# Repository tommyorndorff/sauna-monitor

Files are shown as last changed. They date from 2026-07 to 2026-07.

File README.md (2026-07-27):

# Wi-Fi Sauna Temperature Monitor (ESP32 + K-Type Thermocouple)

A DIY remote temperature monitor for a hot sauna. An ESP32 reads a K-type
thermocouple through a MAX31855 amplifier, runs [ESPHome](https://esphome.io), and
reports temperature over Wi-Fi to [Home Assistant](https://www.home-assistant.io),
which pushes a "sauna is ready" notification to your phone when it hits temperature.

Monitor-only build: it reports the temperature, it does not switch the heater.
Remote-starting a hardwired sauna heater is a separate, safety-critical project and
is out of scope here.

---

## Repository layout

The YAML in this guide is the documentation copy. The maintained, CI-validated
sources live in their own files:

| Path | What |
|---|---|
| [`esphome/sauna-monitor.yaml`](esphome/sauna-monitor.yaml) | ESPHome device config (copy `secrets.yaml.example` → `secrets.yaml`) |
| [`homeassistant/packages/sauna_monitor.yaml`](homeassistant/packages/sauna_monitor.yaml) | Home Assistant package: arming helper + notification automations |
| [`enclosure/`](enclosure/) | 3D-printable enclosure (parametric OpenSCAD) + STLs |
| [`docs/BOM.md`](docs/BOM.md) | Bill of materials with links |
| [`.github/workflows/ci.yml`](.github/workflows/ci.yml) | CI: yamllint + ESPHome + Home Assistant config validation |

---

## Design decisions

- The ESP32 lives outside the hot room. Its silicon and Wi-Fi front-end top out
  around 85 °C, so it cannot survive sauna air. Only the thermocouple probe and its
  lead go into the sauna; the electronics sit in a sealed box on a cool exterior wall.
- K-type thermocouple, not a DS18B20. A DS18B20 is rated to ~125 °C and its cable
  jacket is often the weak point near a sauna ceiling. A K-type probe with a high-temp
  lead handles any sauna temperature with margin. The tradeoff is accuracy
  (~±2 °C vs ±0.5 °C), which does not matter for "is it ready yet."
- IP-rated enclosure protects against outdoor weather and sauna humidity. IP rating is
  about water, not heat, so box placement still matters.

Signal chain: K-type probe → MAX31855 (amplifier + cold-junction compensation) →
SPI → ESP32 → Wi-Fi → Home Assistant.

---

## Bill of materials

Full parts list with purchase links: [`docs/BOM.md`](docs/BOM.md). Summary:

| # | Part | Spec / notes | Approx. |
|---|---|---|---|
| 1 | ESP32 dev board | Standard devkit (ESP32-DevKitC / WROOM-32) | ~$6 |
| 2 | MAX31855 K-type amplifier breakout | 3.3 V logic, SPI, read-only. Genuine MAX31855 preferred; some clones ship a MAX6675 (works, lower resolution) | $5–15 |
| 3 | K-type thermocouple probe | Ungrounded, high-temp lead (fiberglass / stainless braid, ≥400 °C). Threaded or ring-terminal tip for mounting | $8–15 |
| 4 | K-type extension wire/connector | Only if the probe lead won't reach the box. Must be K-type wire, never plain copper | $6 |
| 5 | Enclosure | 3D printed — see [`enclosure/`](enclosure/) (PETG/ASA). Filament + gasket cord only | — |
| 6 | Cable glands (IP68) | One sized to the thermocouple lead OD, one to the power cable OD | $8/pack |
| 7 | Desiccant packs or Gore vent plug | Prevents internal condensation in the sealed box | $5 |
| 8 | High-temp RTV silicone | Rated ~260–300 °C, to seal the wall penetration | $7 |
| 9 | 5 V USB supply + cable | Fed from a GFCI-protected outdoor outlet | $8 |
| 10 | Hookup wire / jumpers + heat-shrink | For the 5 SPI + power lines | $5 |
| 11 | Probe mount hardware | Stainless bracket/bolt to fix the tip near the ceiling | $5 |

Roughly $50–70 beyond the ESP32. Prices vary by vendor; check before buying.

Note: SPI does not use the 4.7 kΩ pull-up resistor that a DS18B20 (1-Wire) build
requires. If you're adapting a DS18B20 guide, drop that resistor.

---

## Wiring

MAX31855 is SPI and read-only, so it uses CLK, MISO (DO), and CS. There is no MOSI.

| MAX31855 pin | ESP32 pin (example) | Notes |
|---|---|---|
| VIN / VCC | 3.3 V | 3.3 V logic board — do not use a 5 V-only module |
| GND | GND | |
| SCK / CLK | GPIO18 | SPI clock |
| DO / SO (MISO) | GPIO19 | data out from the chip |
| CS | GPIO5 | chip select (any free GPIO) |

Thermocouple to the breakout screw terminals — polarity matters:

- K-type convention: yellow = + (positive), red = − (negative).
- Reversed leads read backwards / cold. If the reading moves the wrong way when heated,
  swap the two.
- If extending, splice with K-type wire or a K-type connector only. Plain copper creates
  a second thermocouple junction and a measurement error.

Layout rule: keep the MAX31855 close to the ESP32 (the thermocouple signal is
microvolt-level). Run the thermocouple wire as the long leg into the sauna; do not run
a long SPI cable.

---

## Enclosure, mounting & sealing

- Mount the box on a cool, shaded exterior surface of the sauna building.
- Probe tip goes a hand's width (~10–15 cm) below the ceiling, ideally above or near the
  heater where the air is hottest — the conventional meaning of "sauna temperature."
- Bring the thermocouple lead into the box through an IP68 gland; seal the wall
  penetration into the sauna with high-temp RTV silicone.
- Drop a desiccant pack (or fit a Gore vent plug) inside the box. A sealed enclosure with
  large temperature swings condenses internally — the classic "waterproof" failure.
- Keep the mains side to code for a wet outdoor location; power from a GFCI outlet.

The printable enclosure and print settings are in [`enclosure/`](enclosure/).

---

## Firmware (ESPHome)

Requires ESPHome 2025.x or newer (the `max31855` platform under the SPI bus). Put your
Wi-Fi credentials in `secrets.yaml`. The maintained config is
[`esphome/sauna-monitor.yaml`](esphome/sauna-monitor.yaml).

```yaml
esphome:
  name: sauna-monitor

esp32:
  board: esp32dev

wifi:
  ssid: !secret wifi_ssid
  password: !secret wifi_password

logger:
api:
  encryption:
    key: !secret api_key   # optional but recommended
ota:
  - platform: esphome

# MAX31855 is read-only: CLK + MISO only, no MOSI
spi:
  clk_pin: GPIO18
  miso_pin: GPIO19

sensor:
  - platform: max31855
    name: "Sauna Temperature"
    cs_pin: GPIO5
    update_interval: 10s
```

After the first flash, confirm the sensor appears in ESPHome logs and reads plausible
room temperature before you seal anything up. It publishes to Home Assistant as
`sensor.sauna_temperature` (°C).

---

## Home Assistant: ready notification

Requires the Home Assistant Companion app on your phone for the `notify.mobile_app_*`
service. Rename `notify.mobile_app_your_phone` to your device. The maintained package is
[`homeassistant/packages/sauna_monitor.yaml`](homeassistant/packages/sauna_monitor.yaml).

### Version A — basic (fires on every crossing)

```yaml
alias: Sauna Ready
description: Notify when the sauna reaches usable temperature
triggers:
  - trigger: numeric_state
    entity_id: sensor.sauna_temperature
    above: 80          # °C  (80 °C ≈ 176 °F) — set to taste
    for:
      minutes: 2       # must hold above threshold to ignore spikes
conditions: []
actions:
  - action: notify.mobile_app_your_phone
    data:
      title: "🔥 Sauna is ready"
      message: >
        Sauna hit {{ states('sensor.sauna_temperature') }} °C — good to go.
mode: single
```

The `numeric_state` trigger is edge-triggered, so it fires only on the upward crossing,
not continuously while the sauna holds temperature. The `for: 2 minutes` guards against a
brief overshoot firing it early.

### Version B — arming helper (recommended)

Prevents mid-session false alerts (for example, temp dips after throwing water, then
climbs back through 80 °C). You arm it when you start the heater; it self-disarms after
alerting.

1. Create the helper — Settings → Devices & Services → Helpers → Toggle →
   name it `Sauna Heating` (entity `input_boolean.sauna_heating`). Flip it on when you
   start the heater (dashboard button, phone, or a voice assistant).

2. Ready automation (armed, one-shot):

```yaml
alias: Sauna Ready (armed)
triggers:
  - trigger: numeric_state
    entity_id: sensor.sauna_temperature
    above: 80
    for:
      minutes: 2
conditions:
  - condition: state
    entity_id: input_boolean.sauna_heating
    state: "on"
actions:
  - action: notify.mobile_app_your_phone
    data:
      title: "🔥 Sauna is ready"
      message: >
        Sauna hit {{ states('sensor.sauna_temperature') }} °C — good to go.
  - action: input_boolean.turn_off        # disarm so it won't re-alert this session
    target:
      entity_id: input_boolean.sauna_heating
mode: single
```

3. Auto-disarm on cooldown (clears state if you armed but never went / cancelled):

```yaml
alias: Sauna Disarm on Cooldown
triggers:
  - trigger: numeric_state
    entity_id: sensor.sauna_temperature
    below: 40
    for:
      minutes: 10
conditions:
  - condition: state
    entity_id: input_boolean.sauna_heating
    state: "on"
actions:
  - action: input_boolean.turn_off
    target:
      entity_id: input_boolean.sauna_heating
mode: single
```

### Fahrenheit message (without changing firmware)

Replace the `message:` line in any automation above with:

```yaml
      message: >
        Sauna hit {{ (states('sensor.sauna_temperature') | float * 9/5 + 32) | round(0) }} °F — good to go.
```

### Optional refinements

- Notify all devices: use `action: notify.notify` instead of a single mobile app.
- Announce out loud: add a TTS action to a nearby speaker.
- Auto-arm instead of manual: trigger on temperature rising through a low threshold.
  Simpler to use but more prone to misfires, so manual arming is the default here.

---

## Bring-up checklist

1. Flash ESPHome; confirm the sensor reads room temp on the bench.
2. Warm the probe tip by hand; the reading should rise. If it drops, swap thermocouple polarity.
3. Wire, gland, and seal only after the reading is verified.
4. Add desiccant, close the box, mount it on a cool exterior wall.
5. Run the sauna once and confirm the notification fires at your target temp.

---

## Safety notes

- This device monitors only. It does not and should not control the heater.
- Respect your heater's built-in thermostat, overheat limiter, and auto-shutoff timer.
- All mains wiring to local code; outdoor/wet locations require GFCI protection.
- Never leave a heating sauna unattended, and keep combustibles off the stones.

---

## License

MIT — no warranty. Provided as-is; you are responsible for your own electrical work
and safety.

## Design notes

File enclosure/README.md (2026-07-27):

# 3D-printed enclosure

Parametric OpenSCAD enclosure for the electronics (ESP32 devkit + MAX31855
breakout). Print-ready STLs are checked in; the `.scad` is the source for
adjusting the fit.

Exterior mount only. This box bolts to a cool, shaded outside wall of the sauna
building. It must not go inside the hot room; the ESP32 tops out around 85 °C.
Only the thermocouple probe and its high-temp lead enter the sauna.

## Files

| File | Print orientation |
|---|---|
| `sauna-monitor-enclosure-base.stl` | as-is, floor on the bed; no supports |
| `sauna-monitor-enclosure-lid.stl` | mating face up (flat outer face on the bed) |
| `sauna-monitor-enclosure-gasket.stl` | flat on the bed; print in TPU (optional, see below) |
| `enclosure.scad` | parametric source |

## Waterproofing features (IP65-ish intent)

Gasket-and-screws design, not a hermetic seal:

- Gasket groove in the lid mating face (`gasket_groove_w = 2.4`,
  `gasket_groove_d = 1.6`). Seat either ~2 mm silicone O-ring cord or the printed
  TPU gasket (see below).
- Screw-down lid, 4× M3 corner screws into captive bosses.
- Two IP68 cable-gland holes on the front wall: PG7 (~12.5 mm) for the thermocouple
  lead, PG9 (~15.2 mm) for the USB power cable.
- Gore-style vent plug: a ~12 mm (M12) hole in the rear wall (`enable_vent = true`)
  to equalize pressure and vent humidity instead of relying on a loose desiccant
  pack. Set `enable_vent = false` to omit it and use desiccant instead.
- External mounting ears with 5 mm wall-screw holes.

## Print settings

Outdoor, humid, sun-exposed location. Do not use PLA; it creeps and warps in
heat and UV.

- Material: PETG (default) or ASA (better UV/heat resistance).
- Nozzle / bed: per filament — PETG ~240 °C / 80 °C, ASA ~250 °C / 100 °C (enclosed printer for ASA).
- Layer height: 0.2 mm.
- Walls / perimeters: 4 (≥1.6 mm) for water resistance and screw-boss strength.
- Top/bottom layers: 5+ for a watertight floor and lid.
- Infill: 20–30 %.
- Supports: none. The base prints floor-down; the lid prints mating-face-up.

## Gasket

Two options for the seal in the lid groove:

- Silicone O-ring cord (~2 mm), cut to length. Simplest.
- Printed TPU gasket (`sauna-monitor-enclosure-gasket.stl`), if you'd rather not
  source cord. It follows the groove centreline, sits 0.2 mm under-width so it
  seats, and stands `gasket_proud` (1.0 mm) above the groove to compress under the
  lid.

TPU gasket print settings:

- Material: TPU (95A is fine).
- Layer height: 0.2 mm; walls only (it's thin), ~3 perimeters, 0–15 % infill.
- Slow it down (20–30 mm/s) and disable retraction if your slicer allows; thin TPU
  rings print cleaner slow.
- No supports.

Tune fit with `gasket_fit_clear` (per-side clearance) and `gasket_proud`
(compression height) in `enclosure.scad`.

## Adjusting the fit

Edit the variables at the top of `enclosure.scad`, then re-export:

```bash
# base (with vent plug), lid, and TPU gasket, high facet quality
openscad -o sauna-monitor-enclosure-base.stl   -D 'part="base"'   -D '$fn=96' --export-format binstl enclosure.scad
openscad -o sauna-monitor-enclosure-lid.stl    -D 'part="lid"'    -D '$fn=96' --export-format binstl enclosure.scad
openscad -o sauna-monitor-enclosure-gasket.stl -D 'part="gasket"' -D '$fn=96' --export-format binstl enclosure.scad
```

Measure your actual boards first and set the mounting-hole spacings before a final
print:

- ESP32: `esp_hole_sx`, `esp_hole_sy`, and position `esp_center_x/y`
- MAX31855: `max_hole_sx`, `max_hole_sy`, and position `max_center_x/y`

Other variables: `inner_l/w/h` (cavity size), `wall`, `gland_tc_d` / `gland_pwr_d`
(gland hole sizes), `vent_hole_d`, `enable_vent`.

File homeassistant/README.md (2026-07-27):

# Home Assistant configuration

The sauna-ready notification logic is in [`packages/sauna_monitor.yaml`](packages/sauna_monitor.yaml),
a self-contained Home Assistant [package](https://www.home-assistant.io/docs/configuration/packages/).
It provides:

- `input_boolean.sauna_heating` — the arming helper, flipped on when you start the heater.
- `Sauna Ready (armed)` — one-shot notification when the temperature holds above 80 °C
  while armed; disarms itself after alerting.
- `Sauna Disarm on Cooldown` — clears the armed state if you never went.

## Install

1. Copy `packages/sauna_monitor.yaml` into your Home Assistant config under a `packages/`
   directory (for example `/config/packages/sauna_monitor.yaml`).
2. Enable packages in `configuration.yaml`:

   ```yaml
   homeassistant:
     packages: !include_dir_named packages
   ```

3. Replace `notify.mobile_app_your_phone` with your device's notify service
   (requires the Home Assistant Companion app).
4. Reload YAML: Developer Tools → YAML → All (or restart).

The sensor `sensor.sauna_temperature` is published by the ESP32 — see
[`../esphome/`](../esphome/).

## Prerequisites

- Home Assistant Companion app on the phone (for `notify.mobile_app_*`).
- The ESPHome device online and its sensor discovered in Home Assistant.

## Fahrenheit message

Replace the `message:` line with:

```yaml
message: >
  Sauna hit {{ (states('sensor.sauna_temperature') | float * 9/5 + 32) | round(0) }} °F — good to go.
```

## Notes

- The `configuration.yaml` in this folder is a minimal file used only for CI
  validation (`hass --script check_config`). Do not copy it over a real install;
  merge the `packages:` line into your existing config instead.
- A simpler unarmed version (fires on every upward crossing) and other refinements
  are described in the top-level [`README.md`](../README.md#home-assistant-ready-notification).

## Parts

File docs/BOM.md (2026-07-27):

# Bill of Materials

Roughly $50–70 beyond the ESP32. The links are representative product/search links,
not endorsements. Check specs, logic voltage, and price with your own vendor before
buying.

The enclosure is 3D printed from [`../enclosure/`](../enclosure/), so it is not a
purchased line item. You need filament (PETG or ASA — see the enclosure README) and
a silicone gasket cord.

| # | Part | Spec / notes | Approx. | Where to look |
|---|---|---|---|---|
| 1 | ESP32 dev board | Standard devkit (ESP32-DevKitC / WROOM-32) | ~$6 | [Espressif DevKitC](https://www.espressif.com/en/products/devkits/esp32-devkitc) · [Adafruit](https://www.adafruit.com/product/3269) · [Amazon search](https://www.amazon.com/s?k=ESP32+DevKitC) |
| 2 | MAX31855 K-type amplifier breakout | 3.3 V logic, SPI, read-only. Genuine MAX31855 preferred; some clones ship a MAX6675 (works, lower resolution) | $5–15 | [Adafruit #269](https://www.adafruit.com/product/269) · [datasheet](https://www.analog.com/media/en/technical-documentation/data-sheets/MAX31855.pdf) |
| 3 | K-type thermocouple probe | Ungrounded, high-temp lead (fiberglass / stainless braid, ≥400 °C). Threaded or ring-terminal tip | $8–15 | [Adafruit #3245](https://www.adafruit.com/product/3245) · [Amazon search](https://www.amazon.com/s?k=K-type+thermocouple+high+temperature+probe) |
| 4 | K-type extension wire/connector | Only if the probe lead won't reach the box. Must be K-type wire, never plain copper | $6 | [Amazon search](https://www.amazon.com/s?k=K-type+thermocouple+extension+wire) |
| 5 | Enclosure | 3D printed — see [`../enclosure/`](../enclosure/). Need only filament + gasket | — | [enclosure/](../enclosure/) |
| 6 | Cable glands (IP68) | One sized to the thermocouple lead OD, one to the power cable OD (PG7 / PG9 common) | $8/pack | [Amazon search](https://www.amazon.com/s?k=IP68+cable+gland+PG7+PG9) |
| 7 | Desiccant packs or Gore vent plug | Prevents internal condensation in the sealed box | $5 | [Desiccant](https://www.amazon.com/s?k=silica+gel+desiccant+packs) · [Gore vent plug](https://www.amazon.com/s?k=Gore+M12+vent+plug) |
| 8 | High-temp RTV silicone | Rated ~260–300 °C, to seal the wall penetration | $7 | [Amazon search](https://www.amazon.com/s?k=high+temp+RTV+silicone+300C) |
| 9 | 5 V USB supply + cable | Fed from a GFCI-protected outdoor outlet | $8 | [Amazon search](https://www.amazon.com/s?k=5V+USB+power+supply) |
| 10 | Hookup wire / jumpers + heat-shrink | For the 5 SPI + power lines | $5 | [Amazon search](https://www.amazon.com/s?k=jumper+wires+heat+shrink) |
| 11 | Probe mount hardware | Stainless bracket/bolt to fix the tip near the ceiling | $5 | local hardware |
| 12 | Lid gasket | Either ~2 mm silicone cord, or print the TPU gasket in [`../enclosure/`](../enclosure/) (needs TPU filament) | $6 | [Silicone cord](https://www.amazon.com/s?k=silicone+rubber+cord+2mm) · [TPU filament](https://www.amazon.com/s?k=TPU+filament) |

Note: SPI does not use the 4.7 kΩ pull-up resistor that a DS18B20 (1-Wire) build
requires. If you're adapting a DS18B20 guide, drop that resistor.

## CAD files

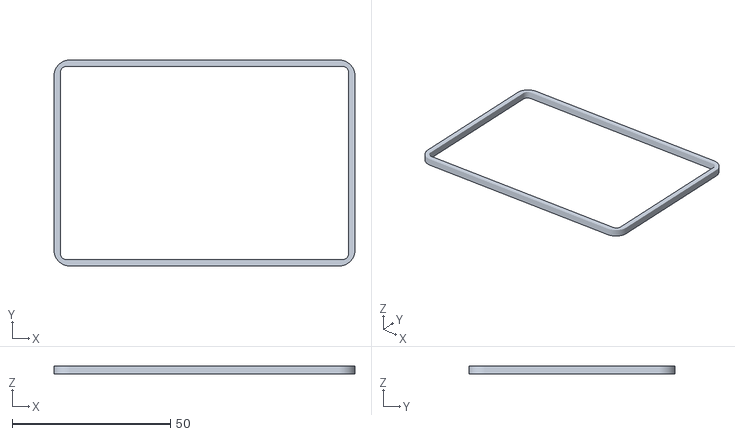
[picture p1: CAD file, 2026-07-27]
enclosure/sauna-monitor-enclosure-gasket.stl
95.0 x 65.0 x 2.60

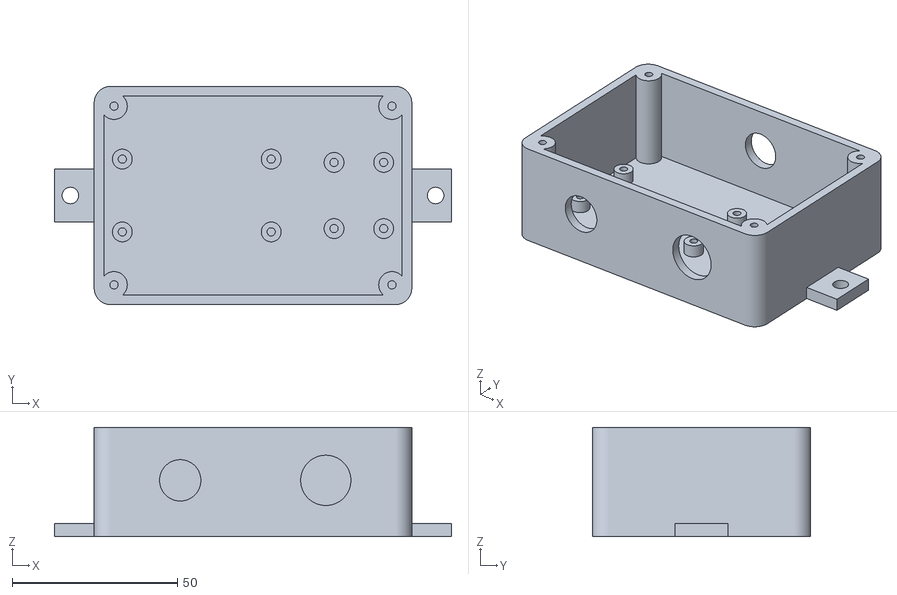
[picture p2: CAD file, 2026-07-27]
enclosure/sauna-monitor-enclosure-base.stl
120.0 x 66.0 x 33.0

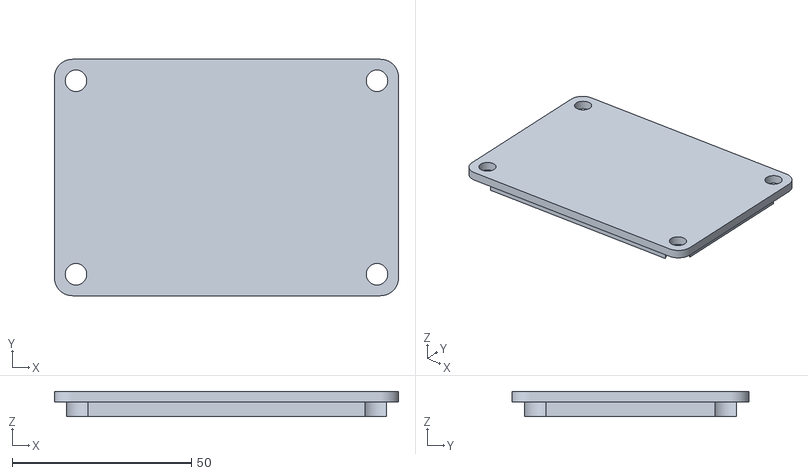
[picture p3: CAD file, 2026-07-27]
enclosure/sauna-monitor-enclosure-lid.stl
96.0 x 66.0 x 7.00

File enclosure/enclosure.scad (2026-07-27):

// ============================================================================
//  Sauna Monitor Enclosure  --  parametric OpenSCAD model
// ----------------------------------------------------------------------------
//  Houses an ESP32 dev board + a MAX31855 K-type thermocouple amplifier for
//  the Wi-Fi Sauna Temperature Monitor project (see repo README).
//
//  IMPORTANT SAFETY / PLACEMENT NOTE:
//    This box is for the *EXTERIOR* mount only. It bolts to a cool, shaded
//    outside wall of the sauna building. It must NEVER be placed inside the
//    hot sauna room -- the ESP32 tops out around 85 C. Only the thermocouple
//    probe and its high-temp lead go into the sauna. This enclosure is
//    designed for outdoor weather + humidity resistance (IP65-ish intent):
//    a gasket groove + screw-down lid, NOT a perfect hermetic seal.
//
//  Standard OpenSCAD only -- no external libraries (no BOSL2 etc.).
//  Helper modules for rounded boxes are defined at the bottom.
//
//  Coordinate convention: geometry is centered on X and Y; Z=0 is the outside
//  bottom of the base. All units are millimetres.
// ============================================================================


// ============================================================================
//  PART SELECTION
// ============================================================================
// "base" = box body only, "lid" = lid only,
// "both" = both laid out side by side for preview (default).
part = "both";


// ============================================================================
//  KEY PARAMETERS  --  edit these to fit your hardware
// ============================================================================

// ---- Render quality -------------------------------------------------------
$fn = 48;              // facets for cylinders/arcs (bump to 96 for final STL)

// ---- Wall / shell ---------------------------------------------------------
wall          = 3.0;   // side wall thickness
floor_th      = 3.0;   // base floor thickness
lid_th        = 3.0;   // lid plate thickness
corner_r      = 5.0;   // external corner radius (rounded box)

// ---- Internal cavity (usable space for the boards) ------------------------
// These set the *interior* clear dimensions. Increase if you add more wiring
// room, a bigger desiccant pack, etc.
inner_l       = 90.0;  // interior length (X)  -- long axis
inner_w       = 60.0;  // interior width  (Y)
inner_h       = 30.0;  // interior height (Z), floor top -> lid mating face

// ---- Lid / base fit -------------------------------------------------------
lip_h         = 4.0;   // depth of the locating lip on the lid
lip_clear     = 0.35;  // clearance so the lip slides into the opening
lid_gap       = 12.0;  // gap between base and lid in the "both" preview layout

// ---- Gasket groove (in the lid mating face) -------------------------------
// A rectangular channel cut into the underside of the lid, sitting over the
// centreline of the base wall. Fill with silicone cord (see README).
gasket_groove_w = 2.4; // groove width  (for ~2 mm silicone cord or the printed TPU gasket)
gasket_groove_d = 1.6; // groove depth

// ---- Printed TPU gasket (part = "gasket") ---------------------------------
// A flexible gasket you print in TPU to seat in the lid groove, as an
// alternative to buying silicone cord. Sits in the groove and stands proud so
// the lid compresses it against the base wall top.
gasket_fit_clear = 0.20; // per-side clearance so the TPU seats in the groove
gasket_proud     = 1.00; // how far the gasket stands above the groove to compress
gasket_w         = gasket_groove_w - 2*gasket_fit_clear; // cross-section width
gasket_h         = gasket_groove_d + gasket_proud;       // total printed height

// ---- Lid corner screws (M3, captive in base corner bosses) ----------------
lid_screw_d        = 3.0;   // nominal M3
lid_screw_clear_d  = 3.4;   // clearance hole in the lid
lid_screw_head_d   = 6.0;   // counterbore for the screw head in the lid
lid_screw_head_h   = 3.0;   // counterbore depth
lid_boss_od        = 8.0;   // corner boss outer diameter in the base
lid_boss_pilot_d   = 2.5;   // pilot hole for M3 self-tapping into the boss
lid_boss_inset     = 6.0;   // boss centre inset from the outer corner
                            // (kept < wall+corner_r so the boss overlaps the
                            //  corner wall for a clean, well-fused union)

// ---- Board mounting standoffs (self-tapping bosses) -----------------------
// Set to M2.5 (pilot ~2.1) or M3 (pilot ~2.5) self-tappers.
standoff_h         = 4.0;   // how far the boards sit above the floor
standoff_od        = 6.0;   // boss outer diameter
standoff_pilot_d   = 2.5;   // pilot hole diameter (M3 self-tap default)

// ESP32 dev board (generic devkit). Mounting-hole spacing between the 4 holes.
// Many DevKitC clones are ~55 x 28 mm; adjust the hole spacing to YOUR board.
esp_hole_sx        = 45.0;  // hole spacing along X
esp_hole_sy        = 22.0;  // hole spacing along Y
esp_center_x       = -17.0; // where the ESP32 sits inside the cavity (X)
esp_center_y       = 0.0;   // (Y)

// MAX31855 breakout (~20 x 25 mm). Adafruit-style board hole spacing.
max_hole_sx        = 15.0;  // hole spacing along X
max_hole_sy        = 20.0;  // hole spacing along Y
max_center_x       = 32.0;  // where the MAX31855 sits inside the cavity (X)
max_center_y       = 0.0;   // (Y)

// ---- Cable glands (IP68) on one side wall ---------------------------------
// PG7 ~ 12.5 mm, PG9 ~ 15.2 mm mounting-hole diameter. Pick per gland.
pg7_hole_d         = 12.5;  // convenience constant
pg9_hole_d         = 15.2;  // convenience constant
gland_tc_d         = pg7_hole_d;  // thermocouple lead gland hole
gland_pwr_d        = pg9_hole_d;  // 5V USB power gland hole
gland_z            = 14.0;  // gland centre height above the floor top
gland_tc_x         = -22.0; // X position of thermocouple gland on the wall
gland_pwr_x        =  22.0; // X position of power gland on the wall

// ---- Optional Gore-style vent plug ----------------------------------------
// Equalises pressure / lets humidity out instead of a loose desiccant pack.
enable_vent        = true;  // set false to rely on a desiccant pack instead
vent_hole_d        = 12.0;  // M12 vent-plug hole (~12 mm)
vent_z             = 16.0;  // vent centre height above the floor top
vent_x             = 0.0;   // vent X position on the (opposite) wall

// ---- External wall-mount ears / flanges -----------------------------------
ear_w              = 16.0;  // ear length along X
ear_depth          = 12.0;  // how far the ear sticks out from the wall (Y)
ear_th             = 4.0;   // ear thickness (Z)
ear_screw_d        = 5.0;   // wall-fixing screw clearance hole in the ear
ear_z              = 0.0;   // ears flush with the base bottom


// ============================================================================
//  DERIVED DIMENSIONS  (do not usually need editing)
// ============================================================================
OL  = inner_l + 2*wall;          // outer length (X)
OW  = inner_w + 2*wall;          // outer width  (Y)
OH  = floor_th + inner_h;        // outer height of the base (Z)
inner_r = max(corner_r - wall, 0.5);  // interior corner radius

eps = 0.01;                      // tiny overlap to avoid coincident faces
sink = 0.6;                      // how far internal posts sink into the floor
                                 // (ensures a clean manifold union, no coincident faces)


// ============================================================================
//  TOP-LEVEL RENDER
// ============================================================================
if (part == "base") {
    base();
} else if (part == "lid") {
    lid();
} else if (part == "gasket") {
    gasket();
} else {
    // "both" -- lay them side by side for preview / plating.
    base();
    translate([OL/2 + OW/2 + lid_gap, 0, 0])
        rotate([0, 0, 90])          // rotate so both fit compactly
            lid();
}
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

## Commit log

2026-07-27 Initial commit: Wi-Fi sauna temperature monitor
    ESP32 + MAX31855 K-type thermocouple monitor running ESPHome, reporting to
    Home Assistant with a "sauna is ready" notification. Monitor-only by design.
    - esphome/: device config (SPI max31855) + secrets template
    - homeassistant/: importable package (arming helper + notification automations)
    - enclosure/: parametric OpenSCAD case + print-ready STLs (base/lid), IP-gland
    holes, gasket groove, and a Gore-style vent plug
    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
    [enclosure.scad, sauna-monitor-enclosure-base.stl, sauna-monitor-enclosure-lid.stl]
2026-07-27 docs: rewrite in plain tone; finalize enclosure
    - Rewrite README, AGENTS.md, BOM, and the HA and enclosure READMEs in a direct
    tone: drop emphasis styling and persuasive framing.
    - Add a Documentation style note to AGENTS.md.
    - Add enclosure/README.md (print settings, parameters, safety).
    - Re-render base/lid STLs at $fn=96; both verified as clean 2-manifolds.
    [sauna-monitor-enclosure-base.stl, sauna-monitor-enclosure-lid.stl]
2026-07-27 enclosure: add printable TPU gasket
    Add a `gasket` part to enclosure.scad and a printed STL. It follows the lid
    groove centreline, sits 0.2 mm under-width to seat, and stands 1.0 mm proud to
    compress under the lid. An alternative to sourcing silicone cord.
    - enclosure/sauna-monitor-enclosure-gasket.stl (print in TPU)
    - Document print settings and fit tuning in the enclosure README
    - BOM: lid gasket is now silicone cord or printed TPU
    [enclosure.scad, sauna-monitor-enclosure-gasket.stl]
